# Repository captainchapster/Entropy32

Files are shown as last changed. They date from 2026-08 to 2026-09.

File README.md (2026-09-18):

# Entropy32

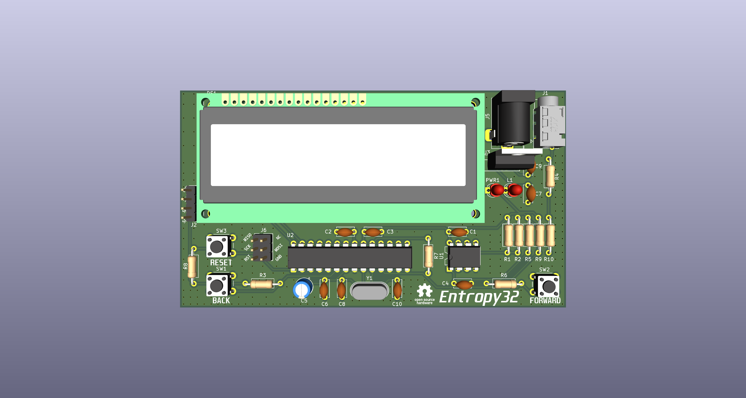
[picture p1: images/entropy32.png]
Assembled PCB


**Entropy32** (aka *The Universe Bifurcator*) is a dedicated Bitcoin seed phrase generator that uses radioactive decay as its entropy source. It's completely open source and designed to be simple, auditable, and buildable by anyone with readily available components.

## Why radioactive decay?

Pseudo-random number generators are deterministic — given the same seed, they always produce the same output. True randomness for something as consequential as a Bitcoin wallet's seed phrase should come from a physical process nobody can predict or manipulate. Radioactive decay is quantum-mechanically random: the timing of individual decay events is fundamentally unpredictable, making it an ideal entropy source for generating cryptographic secrets.

## How it works

1. A Geiger counter detects decay events from a radioactive source (or background) and outputs a pulse via a 3.5mm audio jack.
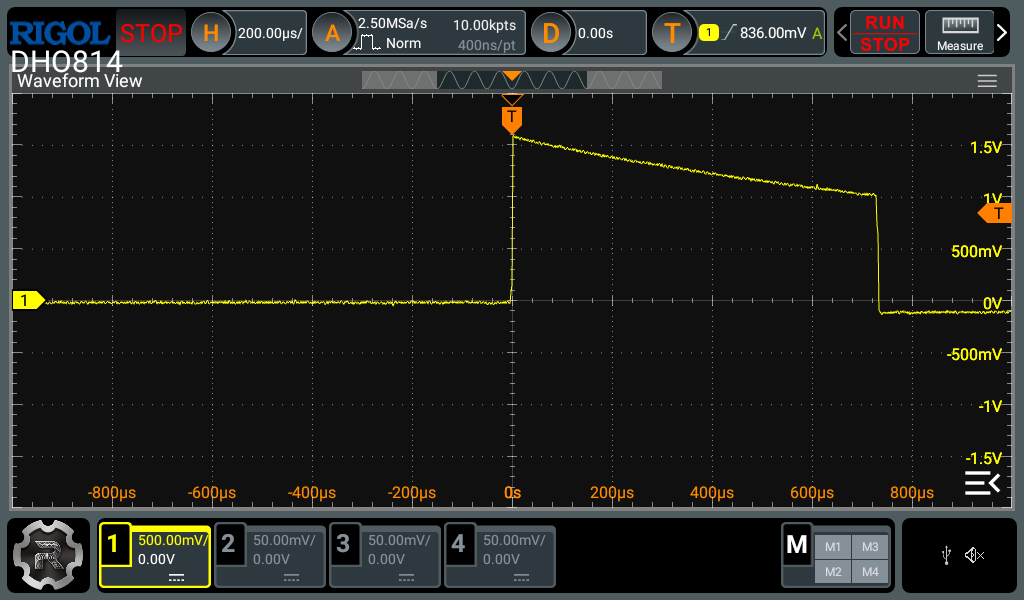
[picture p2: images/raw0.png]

2. An LM393 comparator IC then takes the 0-1.5V pulse and compares it to a bias of ~0.5V via a voltage divider such that if V>0.5V we get HIGH else LOW.
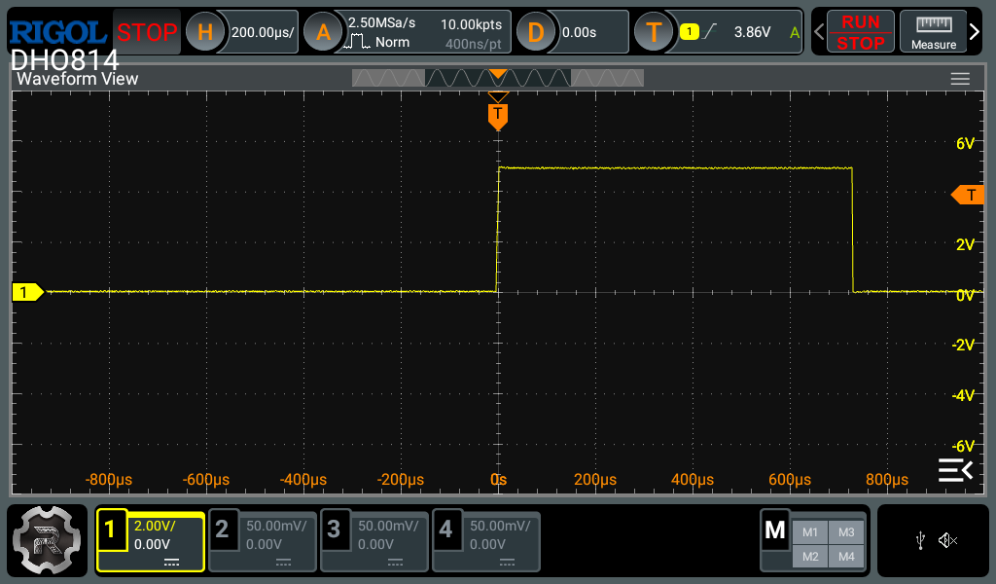
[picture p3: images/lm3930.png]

3. The timing between events is captured and compared in non-overlapping pairs (each inter-arrival time feeds exactly one comparison, so adjacent output bits never share an input interval). Each resulting bit passes two continuous NIST SP 800-90B health tests (Repetition Count Test and Adaptive Proportion Test) before it's fed through SHA-256 conditioning to whiten the raw entropy and remove any bias — if either test trips, the device halts rather than generating a seed from a degraded source.
4. The conditioned entropy is mapped to words from the standard BIP39 English wordlist.
5. A simple button-driven, state-machine UI walks you through generating and displaying your seed phrase — entirely offline, with no wireless connectivity, no persistent storage of the seed, and no software dependencies beyond the device itself.

## Hardware

- Custom PCB built around an [ATmega328P microcontroller](https://ww1.microchip.com/downloads/en/DeviceDoc/Atmel-7810-Automotive-Microcontrollers-ATmega328P_Datasheet.pdf), designed in [KiCad](https://www.kicad.org/)
- Geiger counter module as the entropy source (currently designed to take the 3.5mm output of the [GQ Electronics GMC-320S](https://www.gqelectronicsllc.com/comersus/store/comersus_viewItem.asp?idProduct=5787))
- [LM393 comparator IC](https://www.ti.com/product/LM393)
- Push-button interface for on-device operation
- Serveral common passives i.e. resistors, capacitors, and LEDs
- 7805 voltage regulator 
- 16MHZ crystal oscillator
- 16x2 LCD display with I2C adaptor
- PJ320E 3.5mm audio jack
- DC barrel jack
- header pins

<p align="center">
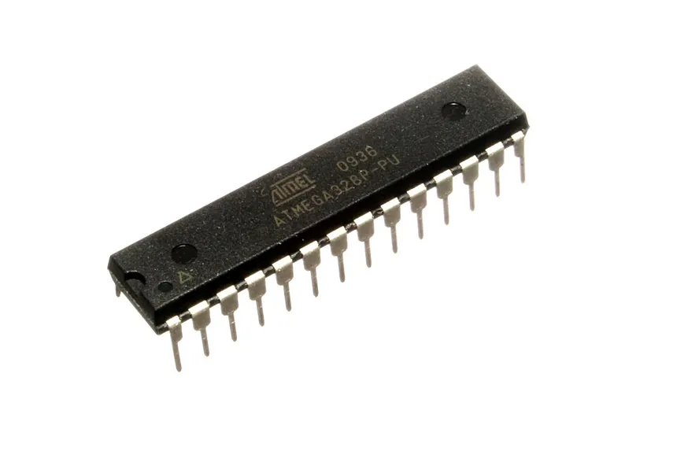
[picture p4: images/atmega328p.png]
ATmega328P
  
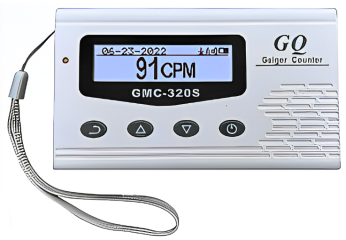
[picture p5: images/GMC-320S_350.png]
GMC-320S Geiger counter
  
</p>

## Repository contents

| File | Purpose |
|---|---|
| `entropy32.ino` | Main firmware — state machine, entropy capture, and UI logic |
| `sha256.h` / `sha256.cpp` | SHA-256 implementation used to condition raw entropy |
| `bip39_wordlist.h` | BIP39 English wordlist, compiled into firmware |
| `button.h` | Button input handling |
| `english.txt` | Source BIP39 wordlist |
| `generate_wordlist.py` | Script to regenerate `bip39_wordlist.h` from `english.txt` |

## Building it yourself

Entropy32 schematic

The Arduino sketch (`entropy32.ino`) and its accompanying `.h`/`.cpp` files must remain in the same top-level folder for the Arduino IDE to compile correctly — it doesn't recurse into subfolders for sketch code. Open `entropy32.ino` in the Arduino IDE, verify your board settings for the ATmega328P, and flash as normal.

## Validation

Entropy quality is being validated against the [NIST SP 800-90B](https://csrc.nist.gov/publications/detail/sp/800-90b/final) methodology for entropy sources used in random bit generation.

## Acknowledgements

- **Cosmographer / BHRIGU** — [bhrigu.io](https://www.bhrigu.io) — identified that the original entropy logic compared each inter-arrival time to the one before it (an overlapping comparison), which correlates adjacent output bits even when the underlying intervals are IID. The firmware now uses non-overlapping interval pairs instead. Thank you for the detailed writeup.

## Disclaimer

This is a hobbyist/educational project. If you use it to generate a real Bitcoin seed phrase, understand the risks: verify the entropy quality yourself, review the code, and never trust a seed-generating device (this one included) with significant funds without independent auditing.

## Licenses

- For firmware/software, see [`MIT LICENSE`](./LICENSE).
- For hardware, see [`CERN-OHL-S v2 LICENSE`](./LICENSE-HARDWARE).

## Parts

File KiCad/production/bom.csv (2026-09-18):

Designator | Footprint | Quantity | Value | LCSC Part #
C1, C9 | C_Disc_D5.0mm_W2.5mm_P5.00mm | 2 | 0.1uF
C10, C8 | C_Disc_D5.0mm_W2.5mm_P5.00mm | 2 | 22pF
C2 | C_Disc_D5.0mm_W2.5mm_P5.00mm | 1 | 100nF
C3, C6 | C_Disc_D5.0mm_W2.5mm_P5.00mm | 2 | 1uF
C4 | C_Disc_D5.0mm_W2.5mm_P5.00mm | 1 | 100pF
C5 | CP_Radial_D5.0mm_P2.00mm | 1 | 4.7uF
C7 | C_Disc_D5.0mm_W2.5mm_P5.00mm | 1 | 0.33uF
DS1 | WC1602A | 1 | WC1602A
J1 | Jack_3.5mm_PJ320E_Horizontal | 1 | AudioJack2
J2 | PinHeader_1x04_P2.54mm_Vertical | 1 | Conn_01x04_Socket
J5 | BarrelJack_Horizontal | 1 | Jack-DC
J6 | PinHeader_2x03_P2.54mm_Vertical | 1 | ICSP
L1 | LED_D3.0mm | 1 | Yellow
PWR1 | LED_D3.0mm | 1 | Green
R1, R3, R5, R6, R8 | R_Axial_DIN0207_L6.3mm_D2.5mm_P10.16mm_Horizontal | 5 | 10k
R10 | R_Axial_DIN0207_L6.3mm_D2.5mm_P10.16mm_Horizontal | 1 | 100k
R2, R4, R7, R9 | R_Axial_DIN0207_L6.3mm_D2.5mm_P10.16mm_Horizontal | 4 | 1k
SW1 | SW_PUSH_6mm | 1 | REV
SW2 | SW_PUSH_6mm | 1 | FWD
SW3 | SW_PUSH_6mm | 1 | RESET
U1 | DIP-8_W7.62mm | 1 | LM393
U2 | DIP-28_W7.62mm | 1 | ATmega328-P
U3 | TO-220-3_Vertical | 1 | L7805
Y1 | Crystal_HC49-4H_Vertical | 1 | 16MHz

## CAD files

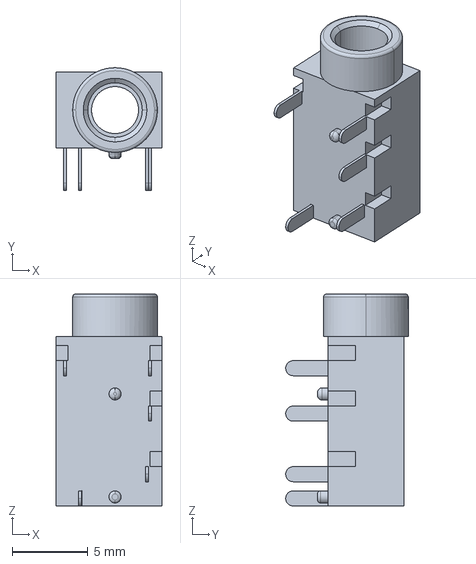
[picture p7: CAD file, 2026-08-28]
KiCad/3d_models/189198069-19-pj-320e/pj-320e.stp
7.00 x 8.10 x 14.0 mm

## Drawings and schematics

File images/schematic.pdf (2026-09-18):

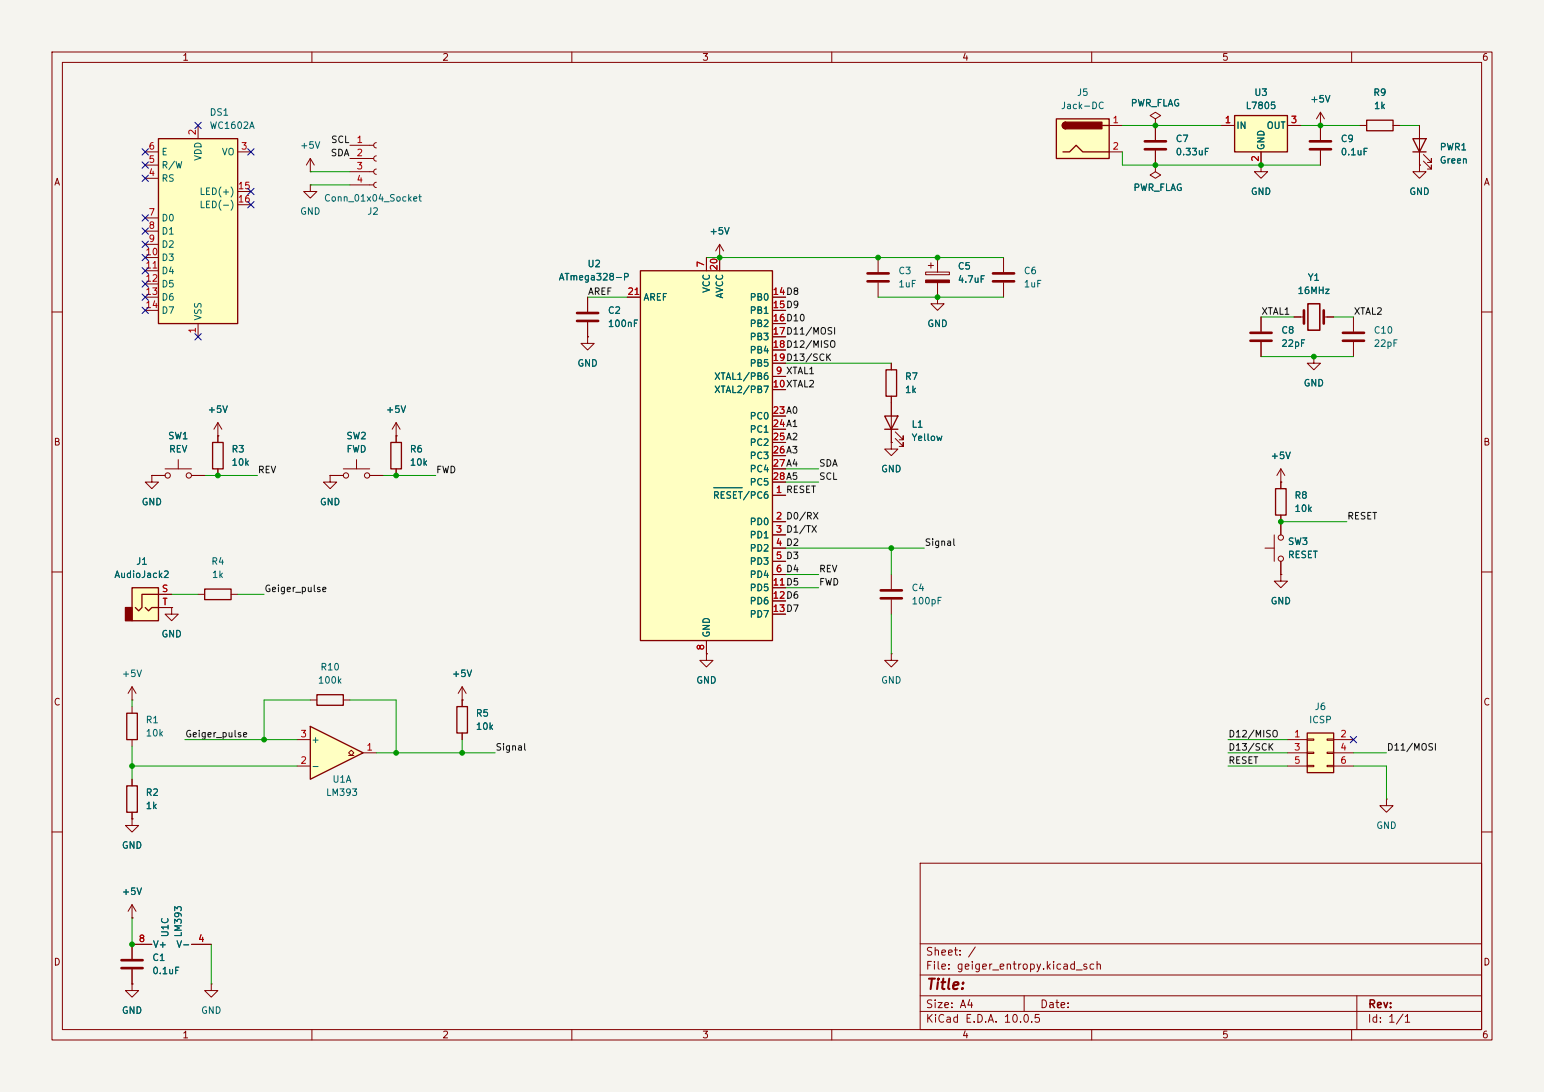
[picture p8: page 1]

Size: A4 | Rev:
KiCad E.D.A. 10.0.5 | Id: 1/1

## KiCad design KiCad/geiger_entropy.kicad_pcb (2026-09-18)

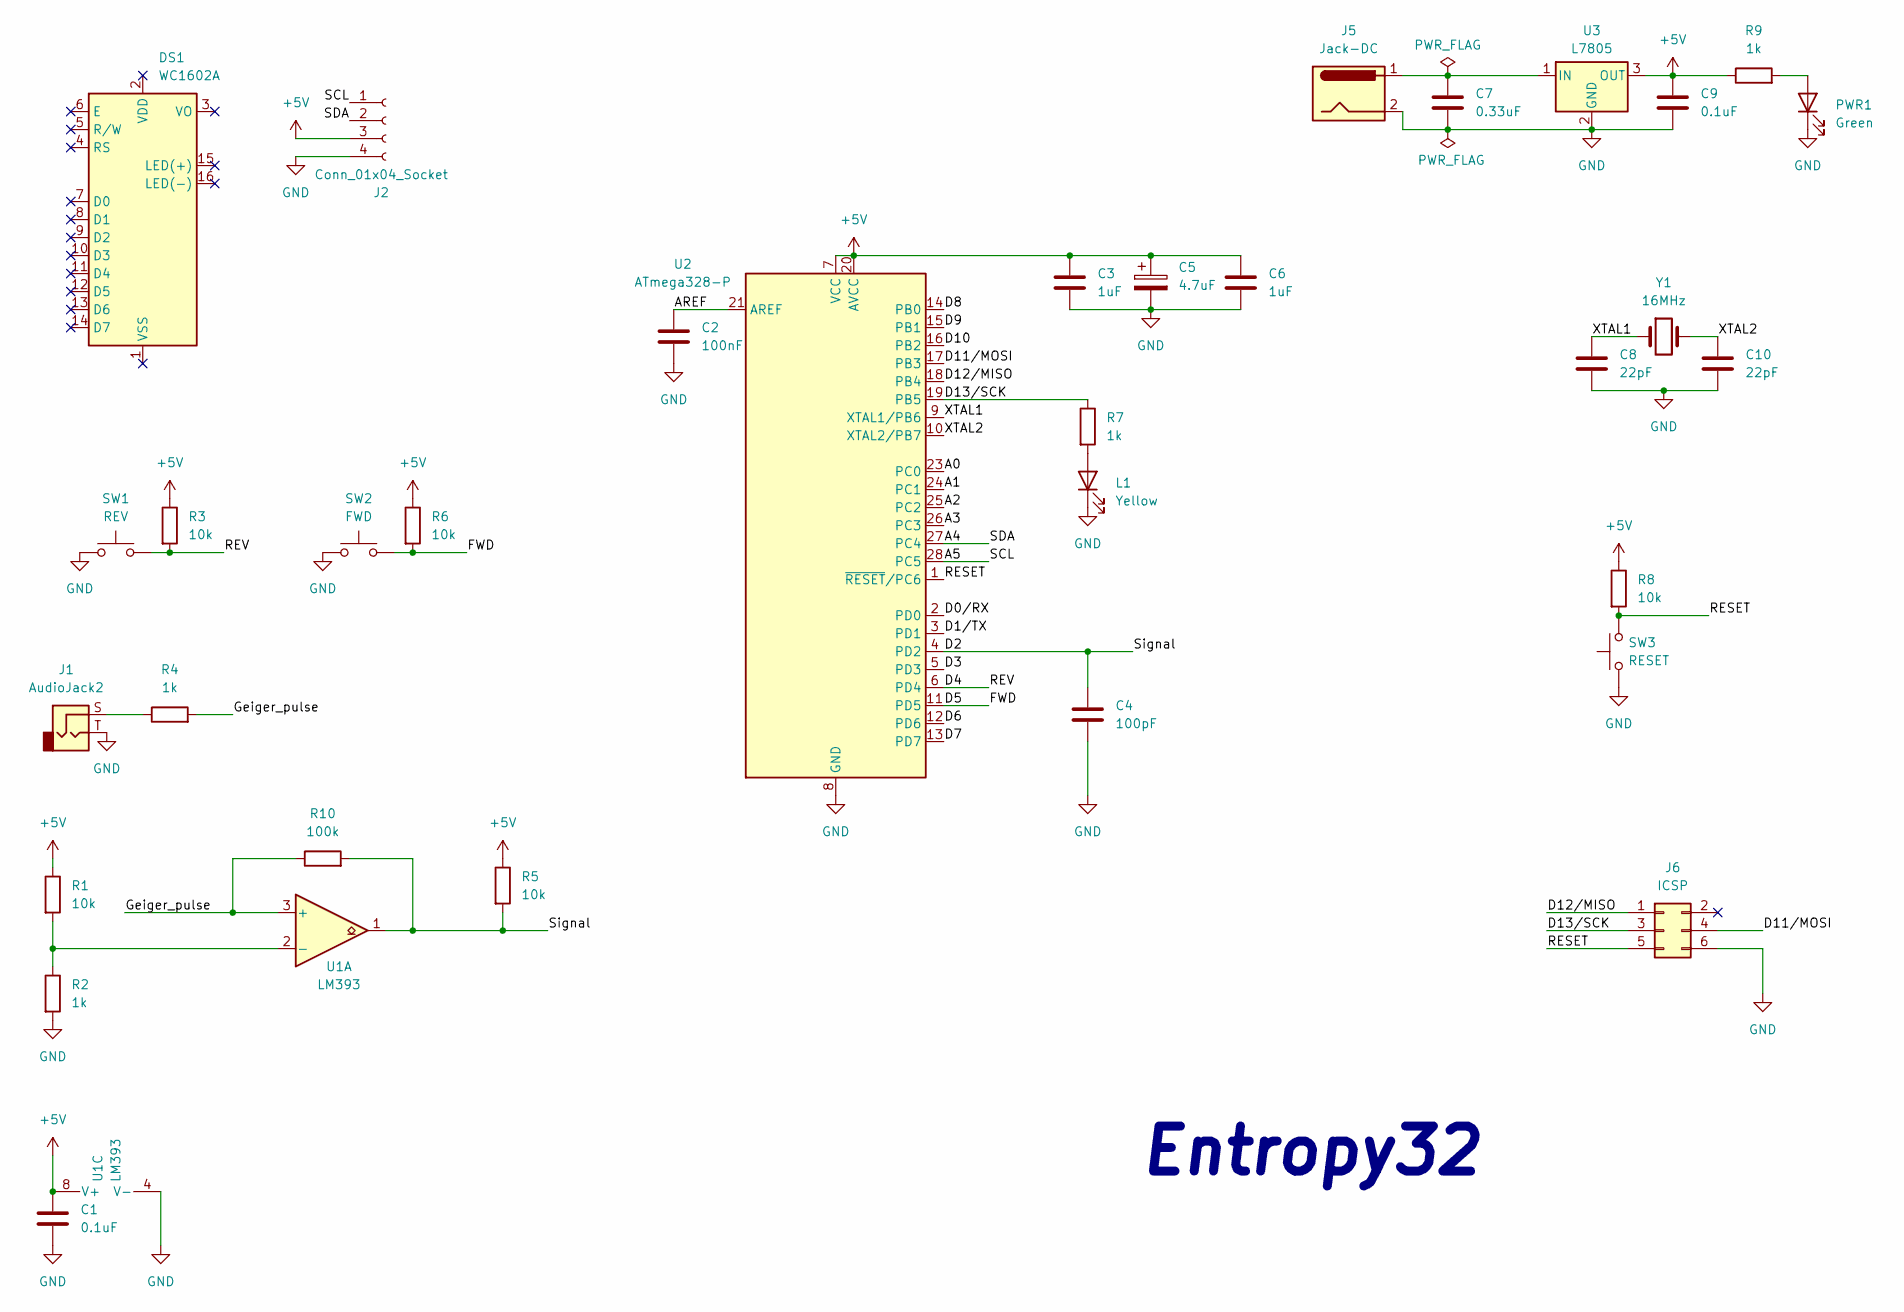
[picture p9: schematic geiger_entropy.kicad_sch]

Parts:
C1, C9: 0.1uF; C_Disc_D5.0mm_W2.5mm_P5.00mm
C2: 100nF; C_Disc_D5.0mm_W2.5mm_P5.00mm
C3, C6: 1uF; C_Disc_D5.0mm_W2.5mm_P5.00mm
C4: 100pF; C_Disc_D5.0mm_W2.5mm_P5.00mm
C5: 4.7uF; CP_Radial_D5.0mm_P2.00mm
C7: 0.33uF; C_Disc_D5.0mm_W2.5mm_P5.00mm
C8, C10: 22pF; C_Disc_D5.0mm_W2.5mm_P5.00mm
DS1: WC1602A
J1: AudioJack2; Jack_3.5mm_PJ320E_Horizontal
J2: Conn_01x04_Socket; PinHeader_1x04_P2.54mm_Vertical
J5: Jack-DC; BarrelJack_Horizontal
J6: ICSP; PinHeader_2x03_P2.54mm_Vertical
L1: Yellow; LED_D3.0mm
PWR1: Green; LED_D3.0mm
R1, R3, R5, R6, R8: 10k; R_Axial_DIN0207_L6.3mm_D2.5mm_P10.16mm_Horizontal
R2, R4, R7, R9: 1k; R_Axial_DIN0207_L6.3mm_D2.5mm_P10.16mm_Horizontal
R10: 100k; R_Axial_DIN0207_L6.3mm_D2.5mm_P10.16mm_Horizontal
SW1: REV; SW_PUSH_6mm
SW2: FWD; SW_PUSH_6mm
SW3: RESET; SW_PUSH_6mm
U1: LM393; DIP-8_W7.62mm
U2: ATmega328-P; DIP-28_W7.62mm
U3: L7805; TO-220-3_Vertical
Y1: 16MHz; Crystal_HC49-4H_Vertical

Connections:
+5V: C1.1, C3.1, C5.1, C6.1, C9.1, J2.3, R1.1, R3.1, R5.1, R6.1, R8.1, R9.1, U1.8 (V+), U2.7 (VCC), U2.20 (AVCC), U3.3 (OUT)
/A0: U2.23 (PC0)
/A1: U2.24 (PC1)
/A2: U2.25 (PC2)
/A3: U2.26 (PC3)
/A4: J2.2, U2.27 (PC4)
/A5: J2.1, U2.28 (PC5)
/AREF: C2.1, U2.21 (AREF)
/D0/RX: U2.2 (PD0)
/D1/TX: U2.3 (PD1)
/D2: C4.1, R5.2, R10.2, U1.1, U2.4 (PD2)
/D3: U2.5 (PD3)
/D4: R3.2, SW1.2, U2.6 (PD4)
/D5: R6.2, SW2.2, U2.11 (PD5)
/D6: U2.12 (PD6)
/D7: U2.13 (PD7)
/D8: U2.14 (PB0)
/D9: U2.15 (PB1)
/D10: U2.16 (PB2)
/D11/MOSI: J6.4, U2.17 (PB3)
/D12/MISO: J6.1, U2.18 (PB4)
/D13/SCK: J6.3, R7.1, U2.19 (PB5)
/Geiger_pulse: R4.2, R10.1, U1.3 (+)
/RESET: J6.5, R8.2, SW3.2, U2.1 (~RESET/PC6)
/XTAL1: C8.1, U2.9 (XTAL1/PB6), Y1.1
/XTAL2: C10.1, U2.10 (XTAL2/PB7), Y1.2
GND: C1.2, C2.2, C3.2, C4.2, C5.2, C6.2, C7.2, C8.2, C9.2, C10.2, J1.T, J2.4, J5.2, J6.6, L1.1 (K), PWR1.1 (K), R2.2, SW1.1, SW2.1, SW3.1, U1.4 (V-), U2.8 (GND), U2.22 (GND), U3.2 (GND)
unnamed: J1.S, R4.1
unnamed: L1.2 (A), R7.2
unnamed: PWR1.2 (A), R9.2
unnamed: R1.2, R2.1, U1.2 (-)
unnamed: C7.1, J5.1, U3.1 (IN)

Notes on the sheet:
Entropy32

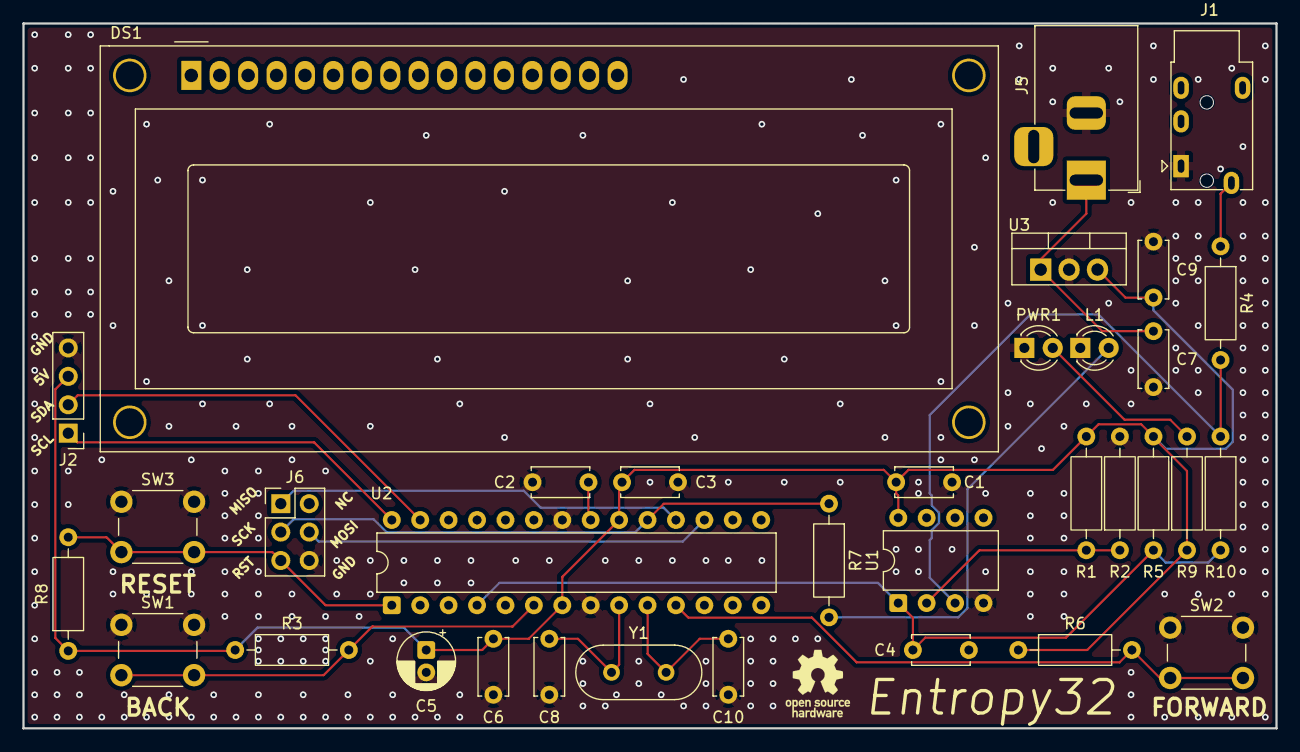
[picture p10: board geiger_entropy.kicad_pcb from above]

Board: 2 copper layers, 112.0 x 63.0 mm, 34 parts (0 on the bottom side), 20 nets.

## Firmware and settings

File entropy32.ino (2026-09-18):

/*
 * Entropy32 - "The Universe Bifurcator"
 * ---------------------------------------------------------
 * Geiger-pulse based TRNG -> BIP39 seed phrase generator
 *
 * Hardware:
 *   - ATmega328P
 *   - 16x2 LCD via I2C backpack (SDA=A4, SCL=A5)
 *   - Processed Geiger pulses (post-LM393) on D2 (INT0)
 *   - Back button  -> D4 (active LOW, internal pull-up)
 *   - Forward button -> D5 (active LOW, internal pull-up)
 *
 * Entropy method:
 *   1. Capture inter-arrival time between successive Geiger pulses.
 *   2. Compare intervals in non-overlapping pairs (T1,T2) -> bit,
 *      (T3,T4) -> bit, (T5,T6) -> bit, etc:
 *        second longer  -> bit 1
 *        second shorter -> bit 0
 *        equal          -> pair discarded (extremely rare at microsecond
 *                           resolution)
 *      Each interval feeds exactly one comparison. An earlier revision
 *      compared every interval to the one before it (T2 vs T1, then T3
 *      vs T2, ...), which reuses each interval in two consecutive
 *      comparisons and correlates adjacent output bits even when the
 *      underlying intervals are IID (credit: Cosmographer / BHRIGU,
 *      https://www.bhrigu.io, for identifying this). Non-overlapping
 *      pairing costs half the raw bit rate but removes that artifact.
 *   3. Run each comparison-bit through two continuous online health
 *      tests (NIST SP 800-90B 4.4.1/4.4.2 minimal tests, see
 *      runHealthChecks()) before it's added to the pool, and halt
 *      rather than generate a seed if either one trips.
 *   4. Collect a raw pool of comparison-bits (RAW_POOL_BITS).
 *   5. Whiten/condition the raw pool with SHA-256 to remove any
 *      residual structure (dead-time correlation, count-rate drift, etc).
 *   6. Follow the standard BIP39 process on the conditioned entropy:
 *      compute checksum = first ENT/32 bits of SHA256(entropy),
 *      append it, split into 11-bit chunks, map each chunk to a
 *      word in the official 2048-word list.
 *
 * IMPORTANT / CAVEAT:
 *   This is a hobbyist/prototype entropy source. Before trusting output
 *   from this device for a seed that will secure real funds:
 *     - Log raw inter-arrival times over a long run and evaluate them
 *       with the NIST SP 800-90B non-IID min-entropy estimators (not
 *       just SP 800-22 pass/fail randomness tests) to confirm the raw
 *       pool has genuinely enough min-entropy for what you're claiming.
 *     - Consider mixing this source with a second, independently-
 *       validated entropy source (e.g. your avalanche-noise Bifurcator)
 *       before finalizing a seed for anything holding real value.
 *     - Never transcribe a generated phrase for real funds directly off
 *       a device you haven't independently audited end-to-end.
 *
 * Required library:
 *   - LiquidCrystal_I2C (e.g. by johnrickman / Frank de Brabander)
 *     Install via Arduino IDE Library Manager.
 *
 * Required companion files (same sketch folder):
 *   - sha256.h / sha256.cpp   (included, self-contained, no dependency)
 *   - bip39_wordlist.h        (generate with generate_wordlist.py)
 */

#include <Wire.h>
#include <LiquidCrystal_I2C.h>
#include <ctype.h>
#include "sha256.h"
#include "bip39_wordlist.h"
#include "button.h"

// ---------------- Pin assignments ----------------
#define GEIGER_PIN 2   // INT0 - processed pulse edge from LM393
#define BACK_PIN   4
#define FWD_PIN    5

// ---------------- LCD ----------------
// Common addresses are 0x27 or 0x3F - run an I2C scanner sketch once
// if the display doesn't init, and adjust here.
LiquidCrystal_I2C lcd(0x27, 16, 2);

// ---------------- CPM tracking ----------------
#define CPM_WINDOW_SECONDS 60
volatile uint32_t totalPulseCount = 0; // all raw pulses seen by the ISR, unfiltered by MIN_INTERVAL_US

uint16_t cpmSecondBuckets[CPM_WINDOW_SECONDS] = {0};
uint8_t  cpmBucketIdx        = 0;
uint32_t cpmRollingSum       = 0;  // sum of the last <=60 one-second buckets
uint32_t cpmLastPulseSnapshot = 0;
unsigned long cpmLastTickMs  = 0;
uint8_t  cpmSecondsElapsed   = 0;  // caps at CPM_WINDOW_SECONDS; used to scale early readings

// ---------------- Entropy collection ----------------
#define RAW_POOL_BITS    512     // raw comparison-bits collected before offering the menu
#define MIN_INTERVAL_US  200     // reject intervals shorter than this (debounce/glitch guard)

volatile uint8_t  entropyPool[RAW_POOL_BITS / 8]; // bit-packed raw pool
volatile uint16_t poolBitIndex   = 0;
volatile unsigned long lastPulseMicros = 0;
// Non-overlapping pairing state: each interval feeds exactly one
// comparison, so the first interval of a pair is held here until the
// second arrives, then both are discarded (tie or not) before the next
// pair starts. This is what keeps adjacent output bits from sharing an
// input interval - see the "Entropy method" note at the top of this file.
volatile unsigned long firstInterval = 0;
volatile bool haveFirstInterval = false;

// ---------------- Entropy health tests ----------------
// The two continuous minimal health tests from NIST SP 800-90B 4.4.1
// (Repetition Count Test) and 4.4.2 (Adaptive Proportion Test), run on
// every raw comparison bit before it reaches entropyPool. They exist to
// catch a stuck/degraded noise source (dead sensor, jammed comparator,
// stuck-high/low input) at runtime, not to certify entropy quality - that
// still requires the offline SP 800-90B estimation described under
// Validation in the README.
//
// Cutoffs assume a conservative claimed per-bit min-entropy H = 1 (i.e.
// "does this still look like a fair coin flip") and a false-positive
// probability alpha = 2^-20, the NIST-recommended default:
//   RCT cutoff  C = ceil(1 + (-log2(alpha) / H)) = ceil(1 + 20/1) = 21
//   APT cutoff, window W = 512: using the normal approximation to the
//   binomial tail (mean = W/2 = 256, sigma = sqrt(W/4) = 11.31, z for
//   alpha = 2^-20 is ~6.36) gives cutoff ~= 256 + 6.36*11.31 = 328. This
//   is a coarse stand-in for the exact tail sum in the spec - cheap
//   enough for the AVR and conservative enough to still catch a
//   genuinely stuck source.
#define RCT_CUTOFF   21
#define APT_WINDOW   512
#define APT_CUTOFF   328

volatile uint8_t  lastBitValue     = 0;
volatile uint8_t  rctRunLength     = 0;
volatile uint8_t  aptReferenceBit  = 0;
volatile uint16_t aptMatchCount    = 0;
volatile uint16_t aptWindowCount   = 0;
volatile bool     healthTestFailed = false;

// Updates both health tests with one raw comparison bit. Called from
// geigerISR() for every bit, independent of whether entropyPool is full,
// so the source is monitored continuously rather than only while
// collecting. Sets healthTestFailed and never clears it - loop() halts
// the device on the next check, matching the existing boot-time KAT /
// wordlist halt behavior; a power cycle is required to resume.
void runHealthChecks(uint8_t bit) {
  // Repetition Count Test: too many identical bits in a row.
  if (bit == lastBitValue) {
    rctRunLength++;
    if (rctRunLength >= RCT_CUTOFF) healthTestFailed = true;
  } else {
    rctRunLength = 1;
    lastBitValue = bit;
  }

  // Adaptive Proportion Test: one value recurring too often within a
  // window of APT_WINDOW consecutive bits.
  if (aptWindowCount == 0) {
    aptReferenceBit = bit;
    aptMatchCount = 1;
  } else if (bit == aptReferenceBit) {
    aptMatchCount++;
    if (aptMatchCount >= APT_CUTOFF) healthTestFailed = true;
  }
  aptWindowCount++;
  if (aptWindowCount >= APT_WINDOW) aptWindowCount = 0; // start next window
}

void geigerISR() {
  totalPulseCount++;
  unsigned long now = micros();
  if (lastPulseMicros != 0) {
    unsigned long interval = now - lastPulseMicros;
    if (interval >= MIN_INTERVAL_US) {
      if (!haveFirstInterval) {
        firstInterval = interval;
        haveFirstInterval = true;
      } else {
        if (interval != firstInterval) {
          uint8_t bit = (interval > firstInterval) ? 1 : 0;
          runHealthChecks(bit);
          if (poolBitIndex < RAW_POOL_BITS) {
            uint16_t byteIdx   = poolBitIndex >> 3;
            uint8_t  bitOffset = poolBitIndex & 0x07;
            if (bit) entropyPool[byteIdx] |=  (1 << bitOffset);
            else     entropyPool[byteIdx] &= ~(1 << bitOffset);
            poolBitIndex++;
          }
        }
        // Whether or not a bit was emitted, both intervals of this pair
        // are now spent - start the next pair fresh rather than sliding
        // forward by one interval (that sliding is the overlap this
        // scheme exists to avoid).
        haveFirstInterval = false;
      }
      lastPulseMicros = now;
    }
  } else {
    lastPulseMicros = now;
  }
}

// ---------------- Buttons (polled, debounced) ----------------
Button backBtn = { BACK_PIN, HIGH, 0 };
Button fwdBtn  = { FWD_PIN,  HIGH, 0 };
#define DEBOUNCE_MS 30

bool buttonPressed(Button &b) {
  bool reading = digitalRead(b.pin);
  bool pressed = false;

  if (reading != b.lastState &&
      (millis() - b.lastChange) > DEBOUNCE_MS) {

    b.lastChange = millis();

    if (reading == LOW)
      pressed = true;

    b.lastState = reading;
  }

  return pressed;
}

// Blocks until both nav buttons are physically released (plus one
// debounce interval to let contact bounce settle) before the caller
// switches into STATE_SHOW_WORD. That state's page navigation is
// driven by buttonPressed()/fwdBtn/backBtn, which is separate debounce
// state from the raw digitalRead() combo-detection in readMenuAction().
// Without this wait, a button still held down at the exact moment of
// the state switch (very common right after a BACK+FWD combo press, or
// a held BACK press) looks to buttonPressed() like a brand-new press,
// silently skipping the first word of the seed.
void waitForNavButtonsReleased() {
  while (digitalRead(BACK_PIN) == LOW || digitalRead(FWD_PIN) == LOW) {
    delay(5);
  }
  delay(DEBOUNCE_MS);
}

// ---------------- Menu buttons ----------------
//
// BACK alone   = previous
// FWD alone    = next
// BACK + FWD   = select

#define COMBO_WINDOW_MS 150

enum MenuAction {
  MENU_NONE,
  MENU_BACK,
  MENU_FWD,
  MENU_SELECT
};

MenuAction readMenuAction();

bool menuComboPending = false;
bool menuComboHandled = false;
bool menuNavHandled = false;
bool menuFirstWasBack = false;
unsigned long menuFirstPressMs = 0;

MenuAction readMenuAction() {

  bool backDown = (digitalRead(BACK_PIN) == LOW);
  bool fwdDown  = (digitalRead(FWD_PIN)  == LOW);

  // Both buttons pressed = SELECT
  if (backDown && fwdDown) {
    if (!menuComboHandled) {
      menuComboHandled = true;
      return MENU_SELECT;
    }
    return MENU_NONE;
  }

  // Wait for both buttons to be released after SELECT
  if (menuComboHandled) {
    if (!backDown && !fwdDown) {
      menuComboHandled = false;
    }
    return MENU_NONE;
  }

  // A button is currently held down.
  // Don't generate another action until it is released.
  if (backDown || fwdDown) {
    if (!menuComboPending && !menuNavHandled) {
      menuComboPending = true;
      menuFirstWasBack = backDown;
      menuFirstPressMs = millis();
    }

    // Single button held long enough = one navigation action.
    if (menuComboPending && millis() - menuFirstPressMs >= COMBO_WINDOW_MS) {
      menuComboPending = false;
      menuNavHandled = true;
      return menuFirstWasBack ? MENU_BACK : MENU_FWD;
    }

    return MENU_NONE;
  }

  // Both released.
  menuComboPending = false;
  menuNavHandled = false;

  return MENU_NONE;
}

// ---------------- App state machine ----------------
enum AppState {
  STATE_COLLECTING,
  STATE_MENU_LENGTH,
  STATE_SHOW_WORD,
  STATE_DONE,
  STATE_WIPE_CONFIRM
};
AppState state = STATE_COLLECTING;

uint8_t  selectedLength  = 12;   // toggled between 12 / 24 in the menu
uint8_t  wordCount       = 0;
uint16_t wordIndices[24];
uint8_t  currentWordPos  = 0;

// ---------------- SHA-256 boot self-test ----------------
// Known-answer test vector: SHA-256("abc")
// Independently verifiable, e.g.:
//   echo -n "abc" | openssl dgst -sha256
//   python3 -c "import hashlib; print(hashlib.sha256(b'abc').hexdigest())"
const uint8_t KAT_INPUT[3] PROGMEM = { 'a', 'b', 'c' };
const uint8_t KAT_EXPECTED[32] PROGMEM = {
  0xba, 0x78, 0x16, 0xbf, 0x8f, 0x01, 0xcf, 0xea,
  0x41, 0x41, 0x40, 0xde, 0x5d, 0xae, 0x22, 0x23,
  0xb0, 0x03, 0x61, 0xa3, 0x96, 0x17, 0x7a, 0x9c,
  0xb4, 0x10, 0xff, 0x61, 0xf2, 0x00, 0x15, 0xad
};

// Runs the KAT and halts on failure (infinite loop, does not return)
// with a FAIL screen. On success, briefly shows PASS + a short hash
// fingerprint before continuing into normal operation.
void runSHA256SelfTest() {
  lcd.clear();
  lcd.setCursor(0, 0);
  lcd.print("SHA-256 self-");
  lcd.setCursor(0, 1);
  lcd.print("test running...");

  uint8_t katInputRam[3];
  memcpy_P(katInputRam, KAT_INPUT, sizeof(katInputRam));

  SHA256 sha;
  sha.update(katInputRam, sizeof(katInputRam));
  uint8_t digest[32];
  sha.finalize(digest);

  bool pass = true;
  for (uint8_t i = 0; i < 32; i++) {
    uint8_t expectedByte = pgm_read_byte(&KAT_EXPECTED[i]);
    if (digest[i] != expectedByte) {
      pass = false;
      break;
    }
  }

  lcd.clear();
  if (pass) {
    lcd.setCursor(0, 0);
    lcd.print("SHA-256 test:");
    lcd.setCursor(0, 1);
    lcd.print("PASS  ");
    // Show first 4 hex bytes of the digest as a quick visual
    // fingerprint the user can cross-check against the published
    // vector (ba7816bf...) if they want extra confidence.
    for (uint8_t i = 0; i < 4; i++) {
      char hex[3];
      sprintf(hex, "%02x", digest[i]);
      lcd.print(hex);
    }
    delay(1800);
  } else {
    // Do not proceed. A broken conditioning step must never silently
    // feed into seed generation.
    lcd.setCursor(0, 0);
    lcd.print("SHA-256 test:");
    lcd.setCursor(0, 1);
    lcd.print("FAIL - HALTED");
    while (true) {
      // halt indefinitely; user must power-cycle after investigating
      delay(1000);
    }
  }
}

// Verifies every word in BIP39_WORDLIST fits in wordBuf (see drawWordScreen()).
// Halts on boot if a regenerated/modified wordlist ever contains an
// oversized entry, rather than silently overflowing the stack later.
void runWordlistLengthCheck() {
  const uint8_t MAX_WORD_LEN = 9; // must match wordBuf[10] - 1, in drawWordScreen()
  for (uint16_t i = 0; i < 2048; i++) {
    char wordBuf[MAX_WORD_LEN + 2]; // +1 slack so an overlong word still shows as overlong, not corrupts this buffer
    strncpy_P(wordBuf, (PGM_P)pgm_read_word(&(BIP39_WORDLIST[i])), sizeof(wordBuf) - 1);
    wordBuf[sizeof(wordBuf) - 1] = '\0';
    if (strlen(wordBuf) > MAX_WORD_LEN) {
      lcd.clear();
      lcd.setCursor(0, 0);
      lcd.print("Wordlist error:");
      lcd.setCursor(0, 1);
      lcd.print("word too long");
      while (true) { delay(1000); } // halt - do not proceed to entropy collection
    }
  }
}

// ---------------- Setup ----------------
void setup() {
  pinMode(GEIGER_PIN, INPUT);
  pinMode(BACK_PIN, INPUT);
  pinMode(FWD_PIN, INPUT);

  attachInterrupt(digitalPinToInterrupt(GEIGER_PIN), geigerISR, RISING);

  lcd.init();
  lcd.backlight();
  lcd.setCursor(0, 0);
  lcd.print("Entropy32");
  lcd.setCursor(0, 1);
  lcd.print("Booting...");
  delay(600);

  runSHA256SelfTest(); // halts here if the SHA-256 implementation is broken
  runWordlistLengthCheck(); // halts here if bip39_wordlist.h has an oversized entry

  lcd.clear();
  lcd.setCursor(0, 0);
  lcd.print("Entropy32");
  lcd.setCursor(0, 1);
  lcd.print("Collecting...");

  cpmLastTickMs = millis();         
  cpmLastPulseSnapshot = totalPulseCount;  
}

// ---------------- Main loop ----------------
void loop() {
  switch (state) {

    case STATE_COLLECTING:
      updateCollectingScreen();
      // Checked here rather than inside the ISR (which only sets the
      // flag) so a failing source halts before its output ever reaches
      // generatePhrase() - see runHealthChecks().
      if (healthTestFailed) {
        lcd.clear();
        lcd.setCursor(0, 0);
        lcd.print("Health test:");
        lcd.setCursor(0, 1);
        lcd.print("FAIL - HALTED");
        while (true) { delay(1000); } // halt - power cycle to retry
      }
      if (poolBitIndex >= RAW_POOL_BITS) {
        state = STATE_MENU_LENGTH;
        drawMenuScreen();
      }
      break;

    case STATE_MENU_LENGTH: {
      MenuAction action = readMenuAction();

      if (action == MENU_BACK) {
        selectedLength = (selectedLength == 12) ? 24 : 12;
        drawMenuScreen();

      } else if (action == MENU_FWD) {
        selectedLength = (selectedLength == 12) ? 24 : 12;
        drawMenuScreen();

      } else if (action == MENU_SELECT) {
        waitForNavButtonsReleased();
        generatePhrase();
        state = STATE_SHOW_WORD;
        currentWordPos = 0;
        drawWordScreen();
      }

      break;
    }

    case STATE_SHOW_WORD:
      if (buttonPressed(fwdBtn)) {
        if (currentWordPos < wordCount - 1) {
          currentWordPos++;
          drawWordScreen();
        } else {
          state = STATE_DONE;
          drawDoneScreen();
        }
      }
      if (buttonPressed(backBtn)) {
        if (currentWordPos > 0) {
          currentWordPos--;
          drawWordScreen();
        }
      }
      break;

    case STATE_DONE: {
      MenuAction action = readMenuAction();

      if (action == MENU_BACK) {
        waitForNavButtonsReleased();
        state = STATE_SHOW_WORD;
        currentWordPos = wordCount - 1;
        drawWordScreen();

      } else if (action == MENU_SELECT) {
        state = STATE_WIPE_CONFIRM;
        drawWipeConfirmScreen();
      }

      break;
    }

    case STATE_WIPE_CONFIRM: {
      MenuAction action = readMenuAction();

      if (action == MENU_SELECT) {
        wipeSeed();
        state = STATE_COLLECTING;
        lcd.clear();
        lcd.setCursor(0, 0);
        lcd.print("Entropy32");
        lcd.setCursor(0, 1);
        lcd.print("Collecting...");

      } else if (action == MENU_BACK || action == MENU_FWD) {
        // Any single-button press cancels back to the done screen
        // rather than the wipe.
        state = STATE_DONE;
        drawDoneScreen();
      }

      break;
    }
  }
}

// ---------------- Screens ----------------
unsigned long lastCollectDraw = 0;

// Rolls the pulse count into a 60-second sliding window, called once per
// second. During the first 60s after boot the window isn't full yet, so
// we scale the observed rate up proportionally rather than under-report
// (e.g. 5 counts in the first 5 seconds reads as ~60 CPM, not ~5 CPM).
void updateCPMWindow() {
  if (millis() - cpmLastTickMs < 1000) return;
  cpmLastTickMs += 1000;

  noInterrupts();
  uint32_t currentTotal = totalPulseCount;
  interrupts();

  uint32_t deltaThisSecond = currentTotal - cpmLastPulseSnapshot;
  cpmLastPulseSnapshot = currentTotal;

  cpmRollingSum -= cpmSecondBuckets[cpmBucketIdx];
  cpmSecondBuckets[cpmBucketIdx] = (deltaThisSecond > 65535UL) ? 65535 : (uint16_t)deltaThisSecond;
  cpmRollingSum += cpmSecondBuckets[cpmBucketIdx];

  cpmBucketIdx = (cpmBucketIdx + 1) % CPM_WINDOW_SECONDS;

  if (cpmSecondsElapsed < CPM_WINDOW_SECONDS) cpmSecondsElapsed++;
}

uint32_t getCurrentCPM() {
  if (cpmSecondsElapsed == 0) return 0;
  if (cpmSecondsElapsed < CPM_WINDOW_SECONDS) {
    return (cpmRollingSum * CPM_WINDOW_SECONDS) / cpmSecondsElapsed; // extrapolate partial window
  }
  return cpmRollingSum; // full 60s of data = directly CPM
}

// Formats CPM with K/M/G suffixes so the value can never overrun a fixed-
// width LCD field, regardless of count rate. Max output is 6 chars + null
// (e.g. "12.3K", "4.2G") — uint32_t itself tops out around 4.29 billion,
// so the G tier alone covers the entire representable range.
void formatCPM(uint32_t cpm, char* out) {
  const char* suffix = "";
  uint32_t divisor = 1;
  if (cpm >= 1000000000UL)      { suffix = "G"; divisor = 1000000000UL; }
  else if (cpm >= 1000000UL)    { suffix = "M"; divisor = 1000000UL; }
  else if (cpm >= 1000UL)       { suffix = "K"; divisor = 1000UL; }

  if (divisor == 1) {
    sprintf(out, "%lu", cpm); // 0-999, no suffix, max 3 chars
    return;
  }

  uint32_t whole = cpm / divisor;
  if (whole >= 100) {
    // 3-digit whole + suffix = 4 chars; adding a decimal here would hit 6, so we drop it.
    sprintf(out, "%lu%s", whole, suffix);
  } else {
    // Up to "99.9K" = 5 chars, exactly fits the field.
    uint32_t frac = ((cpm % divisor) * 10) / divisor;
    sprintf(out, "%lu.%lu%s", whole, frac, suffix);
  }
}

void updateCollectingScreen() {
  updateCPMWindow(); // ticks once per second, independent of the 250ms LCD throttle below

  if (millis() - lastCollectDraw > 250) {
    lastCollectDraw = millis();

    noInterrupts();
    uint16_t idx = poolBitIndex;
    uint8_t byteSnapshot = (idx > 0) ? entropyPool[(idx - 1) >> 3] : 0;
    interrupts();

    char lastBitChar = '-';
    if (idx > 0) {
      lastBitChar = ((byteSnapshot >> ((idx - 1) & 0x07)) & 1) ? '1' : '0';
    }

    char cpmStr[6];
    formatCPM(getCurrentCPM(), cpmStr);

    char lineBuf[17];
    snprintf(lineBuf, sizeof(lineBuf), "LB: %c CPM: %-5.5s", lastBitChar, cpmStr);
    lcd.setCursor(0, 0);
    lcd.print(lineBuf);

    lcd.setCursor(0, 1);
    lcd.print("Bits: ");
    lcd.print(poolBitIndex);
    lcd.print("/");
    lcd.print(RAW_POOL_BITS);
    lcd.print("   ");
  }
}

void drawMenuScreen() {
  lcd.clear();
  lcd.setCursor(0, 0);
  lcd.print("Seed length:");
  lcd.setCursor(0, 1);
  lcd.print(selectedLength);
}
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

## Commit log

2026-08-28 Fix internal pull up error
    [entropy32.ino]
2026-08-28 Add KiCad files
    [geiger_entropy.kicad_pcb, geiger_entropy.kicad_sch, pj-320e.stp]
2026-08-29 Add BOM and fix signal line debounce issue with a 100pF capacitor - optimise PCB layout
    [BOM.csv, BOM.xlsx, geiger_entropy.kicad_pcb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]
2026-08-29 Update PCB
    [geiger_entropy.kicad_pcb]
2026-08-29 Update schematic
2026-08-29 Update PCB image
2026-08-29 Update PCB and add hardware license
    [geiger_entropy.kicad_pcb, geiger_entropy.kicad_sch]
2026-08-29 Add wave packet logo and update PCB
    [geiger_entropy.kicad_pcb]
2026-09-01 Update PCB and code
    [geiger_entropy.kicad_pcb]
2026-09-01 Update PCB to add hysterisis to the LM393 comparator
    [geiger_entropy.kicad_pcb, geiger_entropy.kicad_sch]
2026-09-01 Update schematics
2026-09-04 Add production files and remove legacy gerbers, bom etc
    [BOM.csv, BOM.xlsx, bom.csv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]
2026-09-18 Modify PCB
    [geiger_entropy.kicad_pcb, geiger_entropy.kicad_sch]
2026-09-18 Update PCB and generate production files
    [bom.csv, designators.csv, geiger_entropy.kicad_pcb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]
2026-09-18 Port entropy source fixes and health checks from Entropy32 Plus
    Fix the overlapping inter-arrival-time comparison in the entropy ISR
    (each interval was reused across two consecutive bit comparisons,
    correlating adjacent output bits even when intervals are IID) by
    switching to non-overlapping interval pairs. Add continuous NIST
    SP 800-90B Repetition Count Test and Adaptive Proportion Test health
    checks on every raw bit, halting the device if the Geiger source looks
    stuck or degraded rather than generating a seed from it.
    Also port two smaller fixes from Plus: a nav-button debounce guard
    that prevented a held button from silently skipping the first seed
    word, and uppercase word display for ea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
    [entropy32.ino]
